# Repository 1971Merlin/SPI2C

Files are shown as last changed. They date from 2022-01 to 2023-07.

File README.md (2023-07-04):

# SPI2C
SPI2C interface hardware and software for the TEC-1 and SC-1 family of Z80 single board computers.

The full [construction article](SPI%20and%20I2C%20Article%20Final.pdf) PDF describes the SPI2C board in detail.

Please see https://github.com/tec1group for information on the TEC computer.

**spi2c_library.asm** contains the current code libraries for interfacing with the SPI2C board. Note the IO ports you choose to use will need to be edite in this file, if you're building for the TEC-1 hardware. The settings are correct for use with the SC-1 as provided.

PS2 Keyboard or Mouse contains sample code and circuit for hooking up a regular IBM PC compatible PS/2 or AT keyboard, or, a PS/2 mouse to the SPI2C.

-------------------------------------------------

The following code examples are early test releases and not all of them use the above library.

**spi_7segs.asm** links an 8 digit, 7-segment display (SPI bus, Duinotech XC-3714) to the SC1. 

**i2c test.asm** code expands on the first sample, adding a DS1307 based clock module (i2c bus, Duinotech XC-4450) which then displays the time on the 7-segment SPI board. The i2c code is also designed to be 'universal', compiling for either the TEC-1 or the SC-1 hardware platforms.

**i2c bus scan.asm** scans the entire i2c bus and displays the address of any detected i2c device on the 7-seg displays. press any key to display the next device. FFh displayed means 'no devices found'.

**5110.asm** displays an image on an SPI bus based 'Nokia 5510' or PCD8544 display, i.e. a standard 84x48 monochrome LCD.

**Game of Life 5110.asm** Game of Life is a cellular automation program developed in 1970. https://en.wikipedia.org/wiki/Conway%27s_Game_of_Life It is a popular routine to reproduce an many computing platforms, as the algorithm is quite simple and memory etc. requirements are also fairly minimal. In this version we use the SPI2C board and the Nokia 5110 LCD display as the output device. The program can be compiled with either a random or a fixed pattern starting point.

**maze 5100.asm** A simple maze program, made famous by the well known Commodore 64 basic code

````10 PRINT CHR$(205.5+RND(1)); : GOTO 10.````

Outputs to the 84x48 "Nokia 5110" LCD display.

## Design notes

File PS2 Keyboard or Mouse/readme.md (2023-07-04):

This is a practical example of putting the SPI2C board to good use. It allows the conection of an AT or PS/2 keyoard, or a PS/2 mouse.

Sample code is provided to read in keystrokes or mouse data, and outputs it to the serial terminal. Note you will need the spi2c_library.asm file from the main SPI2C folder also, to assemble the code yourself.

The following diagram shows how the connectors should be wired. Note that only *ONE* device can be connected at a time - you cannot have both a keyboard and a mouse both connected at the same time.

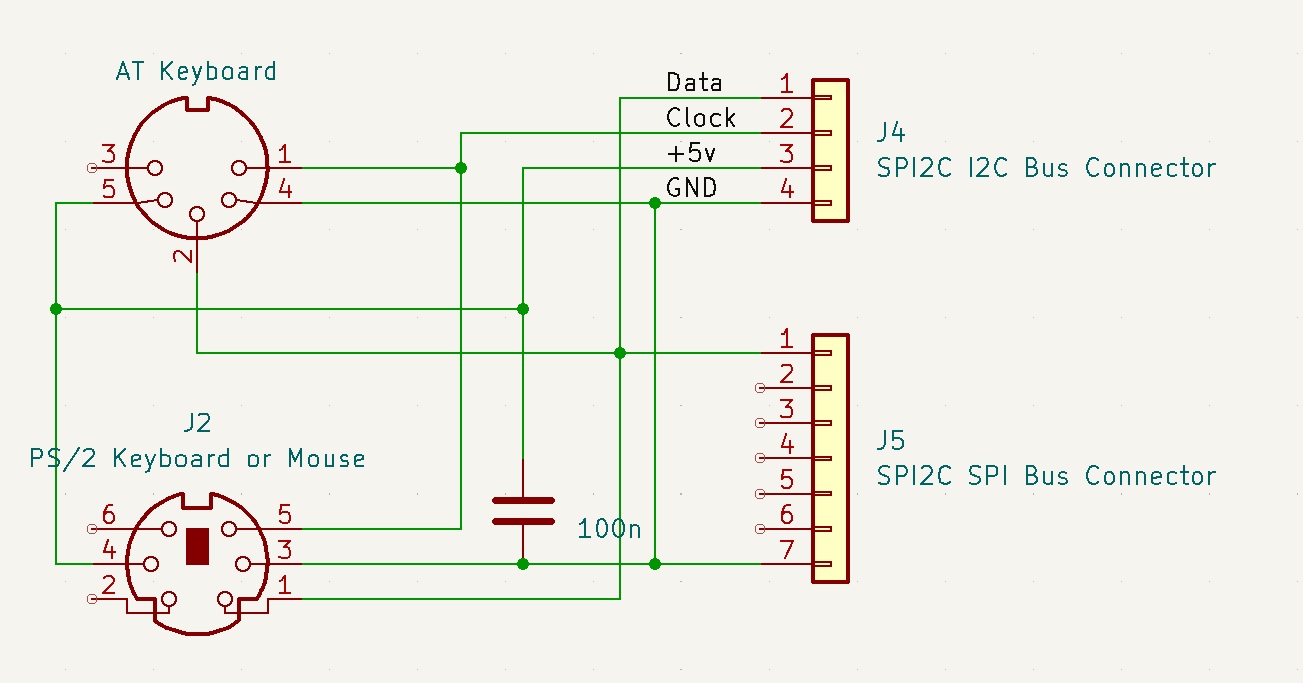
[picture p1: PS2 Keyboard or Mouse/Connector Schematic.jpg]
Connector Schematic


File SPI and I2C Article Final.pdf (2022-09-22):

### Presenting the SPI2C, a simple I/O interface and supporting software for interfacing with

modern peripherals.

### By Craig Hart

One of the limitations of the TEC platform is a lack of 'usable' I/O to communicate with the outside world. TE Issue 14 brought us the I/O board, however this design was a very simple parallel style interface where each I/O pin was either a fixed input or output.
Many modern chips today tend to communicate using bidirectional, serial based signalling protocols – that is, one or two pins are used to transmit and receive data in a serial form. Until now, these devices were not compatible with the TEC-1 or SC-1.
SPI2C implements the two most common interfaces found across a large range of modern peripherals; firstly the SPI or Serial Peripheral Interface bus, and secondly the I

2C
(pronounced I squared C or simply I to C) bus.

In the spirit of TE learning, we have not simply dumped a clever custom chip onto the Z80 bus. Instead, the SPI2C introduces a new design building block for the TEC – a bidirectional IO pin. That is a single pin that can both read and write data under software control. We have built our interfaces using easy to understand 74xxx family TTL logic chips. In this way the entire operation of the design can be understood and followed.
Of course, any hardware is only as good as the software it comes with, and so we are providing supporting software that implements the I

2C

and SPI bus protocols at the most basic level. Full source code is available via Github under an open source license, as are the PCB files. This approach is far more
educational than just ‘talking to a smart controller chip’ or calling a software library you don’t have the source code to.

SPI is a very simple synchronous serial bus. It has a clock(SCLK) line, a chip select(SS) line, and two data lines read(MISO) and write(MOSI).

Don’t be put off by the unfamiliar labels, just mentally substitute (‘In’ or ‘read’ for MISO, and ‘Out’ or ‘write’ for MOSI).
In the above image, the TEC plays the role of Master, and our peripheral device is the Slave. When we say the bus is
synchronous, we simply mean it has a clock(SCLK) line that dictates bus timing.
Data is considered valid when (and only when) the state of the SCLK line changes. Our code can be as fast or slow as we please and it does not matter what frequency the Z80 is running at, or if interrupts are occurring at the same time. The SS line works just like the Chip Select (CS) line we are all familiar with – allowing multiple SPI slave devices to be connected to the bus, but only one device can be active at a time. Each SPI device has its own dedicated SS pin. The MOSI, MISO and SCLK lines are wired in parallel and shared by all devices.
This is where things start to deviate from the familiar TEC world.
The MISO pin is normally held in tristate condition by all devices (nobody is outputting any logic level onto the bus). This is an input pun, so the SPI2C isn’t outputting anything either; therefore a pull-up resistor is supplied to hold the bus at a logic 1 when idle.
Only when a slave device is actively sending data is the pin not tri-stated; the SPI standard says this pin is active LOW, so an SPI slave can pull this pin low to transmit data.
Theoretically, an unlimited number of SPI devices can share a single bus, however there are practical limits to the number of devices; our board offers up to 6 Chip Select lines; hence we can support up to 6 devices in the basic design.
Some slightly non-standard SPI bus devices also have extra control pins for various tasks such as Reset, Backlight enable, mode selection or other custom functions. We can easily support these types of devices by simply adding extra control pins. The SPI2C provides the most common signals.

Duinotech XC-3714: an SPI bus based 8 Digit 7-seg display is available for around $10 from Jaycar etc.

The I

2C bus is a similar yet more advanced version of SPI. With I²C, the whole bus is reduced to just two wires – clock(SCL) and data(SDA).

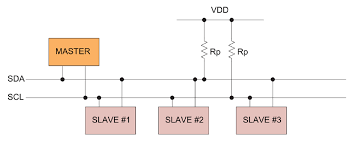
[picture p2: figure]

The bus is also synchronous in nature just like SPI, however a very clever signalling protocol and some smart hardware design is used to eliminate the other control wires completely. Both the clock and data lines use the same active-low-tristate hardware approach as SPI. Chip select is integrated within the bus protocol (each I2C device has a unique 7-bit ‘address’ on the I2C bus), hence the SDA pin performs 3 functions - data in, data out and device select.
SPI offloads all the hard work to software, allowing the hardware to be as simple as possible.

The hardware design can be broken down into several sections, as follows.

The 74HC138 address decoder is functionally similar to the TECs own 74LS138s – except it decodes the IO address range 40h to 7Fh. Note that we ignore address line A0, so every odd port is a duplicate of the preceding even-numbered port. This means port 40h and 41h are an equivalent pair as far as software is concerned (…and port pairs 42h & 43h, 44h and 45h, etc.) so code can address either port and read or write the same device.
Also, since we are ignoring address lines A4 and A5, the I/O ports ‘wrap around’ every 16 addresses, so ports 40h, 50h, 60h and 70h all access the same device.
The reason for this, is that the 74HC138 just doesn’t have enough pins to fully decode just one I/O port. The Z80 has plenty of IO port space so we don’t really care about the overlap.
SC-1
The SPI2C is designed to ‘plug in’ to the SC1’s Expansion connector with no further modifications.

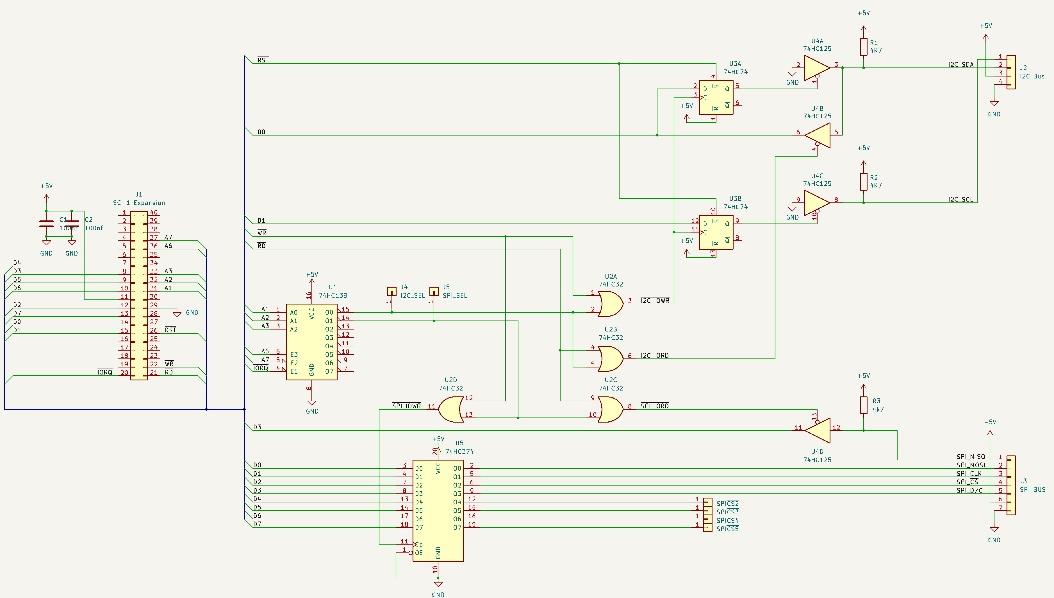
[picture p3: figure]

TEC-1
The 74HC138 chip should be omitted entirely if you wish to use the TEC’s built in IO ports e.g. ports 6 and 7.
Omit the 74HC138 and connect the I2C_SEL and SPI_SEL pins to the TEC’s IO port select pins 6 and 7 instead.

The purpose of the 74HC32 is to take our port select signals from the 74HC138 (or TEC) and combine them with the Z80’s RD and WR signals, to create separate IORead and IOWrite signals.
This is important because different chips are used for the read and write functions, so they need to be selected individually based on whether the Z80 is executing an IN or OUT instruction (IOread or IOwrite cycle).

The 74HC374 is responsible for the write side of the SPI bus.
The SPI_IOWR signal from the 74HC32 enables this chip only when data is written to the SPI port – and all 8 bits are latched by this chip.

Reading from SPI devices is performed by Gate 4 of the 74HC125, and simply gates the MISO pin onto the Z80 data bus during a read cycle. The SPI bus’s MISO pin is held in tri-state (high impedance) mode whenever data is not actively being sent by a slave device, hence this pin is shared by all SPI slave devices.
The 4k7 pull up resistor holds the MISO line high when idle, hence our software will read a ‘1’ whenever the bus is idle. SPI devices only ever output a logic 0 to the MISO pin (*never* a logic 1!!)
Reads are gated onto the Z80 data bus to bit D3 by the 74HC125 in

SPI2C Circuit Diagram response to a decoded IORead cycle.

The I²C controller is a little more complex than SPI. I

2C pins are
active low; therefore held high by pull-up resistors (devices tri-state) whenever idle.
We need to create an SDA pin that supports the following abilities:
a) Be at logic 1 when idle
b) Output a logic 0 or 1 during our writes
c) Read an input 0 or 1 state from a slave device (and not our own previous output) during reads
d) Be independent of the SCL pin
We can’t simply use a 74HC374 here as it is not bidirectional and other 74HC24x family chips won’t suit either as we can’t address pins individually (e.g. have one pin as an output at the same time another pin is set as an input).
To overcome these limitations, we have created two independent one-bit latches using a 74HC74 flip flop and 2 gates from the 74HC125 as our tri-state buffers.
SDA pin
Firstly, the 74HC74 latches our write of bit D0.
If our write is a logic 1, the I²C bus is placed into tri-state as the 7HC74’s output latches this value and the logic 1 sets the HC125’s output to tri-state mode. Since the slave devices are also idle/tri-state, and the 4k7 resistor pulls the bus up to logic 1.
If we write a logic 0, this is latched by the 74HC74 and then a 0 is gated onto the bus by the 74HC125. Note the input of the 74HC125 is wired to ground – hence we can only ever output a 0 to the I2C bus, never a 1.

Input is the same as for SPI – the other 74HC125 gate simply gates the SDA line directly onto the Z80 data bus during an IORead.
The observant amongst you would have noted – to read valid data from the SDA pin, we need to first output a ‘1’ to the SDA pin, in order to set it to tri-state mode; otherwise a bus short
could occur.
The Z80 reset line sets the 74HC74 flipflop to a logic 1 so as to ensure the I2C bus is tri-stated at power up. Our software should also
ensure a bus clash never
occurs.
SCL pin
The SCL pin works the
same way as the SDA pin,
except it is only ever
driven as an output, so we don’t need a ‘125 gate on
this pin, and any data read
of this bit will be undefined.

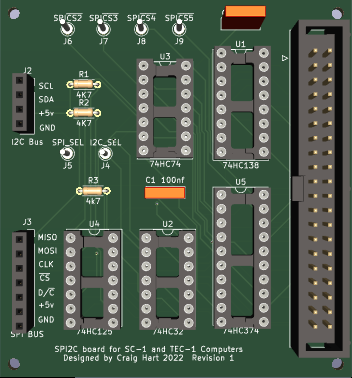
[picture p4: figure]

Any seasoned TEC builder should find assembly straight forward; simply load the parts onto the PCB as shown, the order isn’t critical. However, first decide if you will be building the SC1 version or the TEC version.

The SC1 version is easy – fill all components as shown. The board is designed to plug directly to the expansion header on the SC-1.

Omit the 74HC138 and instead connect I2C_SEL and SPI_SEL pins to the TEC’s IO port select pins for ports 6 and 7.
As the board uses a 40 pin Z80 bus header you will also need to pick up various signals from the TEC

Expansion port and the Z80 CPU. Some soldering to the TEC PCB will be required to pick up all the required signals.
Alternatively, use Craig Jones’ TEC CPU riser board to create an SC-1 style expansion bus connector.
U1 | 74HC138 | (SC-1 only)
U2 | 74HC32
U3 | 74HC74
U4 | 74HC125
U5 | 74HC374
C1 | 100nF
C2 | 100nF
R1 | 4.7k
R2 | 4.7k
R3 | 4.7k
J1 | 40 pin IDC connector
J2 | 4 pin SIL header
J3 | 7 pin SIL header
J4-J9 single pin header

IC Sockets
3 | 14 pin
1 | 16 pin
1 | 20 pin
1 | SPI2C PCB
1 | 40 pin IDC Cable

The SPI2C PCB

The key to this project is the really the software; the hardware itself simply handles the electrical signals, and all the smart control is in the software alone.
The latest versions of all the software as well as schematic, PCB design, supporting datasheets etc. are available at my GitHub site https://github.com/1971Merlin/SPI2C A detailed line by line description of the software is beyond this article, however a quick review as follows:

This program tests basic SPI bus functionality, using a MAX7219 8 digit 7-segment display module such as the Duinotech XC-3714 which is readily available from Jaycar for around $10.
The program simply scrolls a display buffer in RAM across the displays, but it demonstrates several code blocks in doing so – initializing and writing to the SPI bus, as well as managing a simple display buffer.
As a side note, it’s mazing that you can buy EIGHT 7-seg displays, on a PCB, assembled, with a controller chip, pin headers etc. for just ten dollars. To build this yourself from discrete parts would be many times more expensive – hence the value in using these cheap modules and leveraging the wealth of products already out there flooding the Arduino market.

This program builds on spi_7segs, adding support for an I

2C bus based
DS1307 Real Time Clock chip – again we are using the Duniotech XC4450 from Jaycar.
The program implements a simple clock reading from the DS1307 and displaying the time/date on the

MAX7219 displays as well as on the internal 7-seg displays so you can check it is working correctly. Obviously this program introduces the I

2C bus control code, however it is a much more ‘complete’ program that includes several utility routines such as display scanning, keyboard polling. The program contains conditional assembly directives to assemble for either the SC-1 or TEC-1 hardware platforms.

This program uses a cheap 84x48 mono LCD display, also known as a ‘Nokia 5110” display driven form the SPI bus. Once again this is a Jaycar part XC4616 and is less than $20. John Conway’s Game of Life is presented on the LCD, and is a good example of a practical use for the system as a whole.

The code is written and assembled into the final binary using Telemark TASM – the table based assembler, which is available from
https://www.ticalc.org/archives/files/fileinfo/250/25051.html (https://www.ticalc.org/archives/files/fileinfo/250/25051.html)
To compile the code, simply run tasm -80 -g0 filename.asm from a command prompt, and it will output an .obj file in intel hex, and a .lst file which is a text file showing the commented listing and the hex bytes to be keyed in.
I personally take TASM generated .obj file and use the the SC-1’s serial upload feature (Fn 1) to upload the code from a PC at 4800 baud.

Of course you can type the HEX bytes in by hand and write your code with pen, paper and opcode lookup tables the way TE did, but you quickly realise this is not
practical | when | developing
software.
I strongly suggest and encourage use of a modern development environment, so you can focus on writing the software and not mundane tasks like looking up opcodes.
There are numerous development platforms such as Oshonsoft.com and asm80.com available online.

Having introduced some basic routines and the ‘raw’ code, well the sky is the limit in terms of possibilities.
Just about any SPI or I²C bus device can be used – and my goal is to build over time a library of subroutines to support numerous devices.
Any code will of course be published on Github as it is developed. And I encourage readers to become familiar with the various TEC Github resources available in the community. Beyond this, I encourage and welcome you, dear reader, to start experimenting. Feel free to provide feedback, bug fixes and new features via Github and the TEC-1 Facebook group, and lets see what we can grow from here.
I look forward to receiving your input.

All source code and examples are available from my Github

## https://github.com/1971Merlin/SPI2C

All my software is free, open source and GPL licensed.

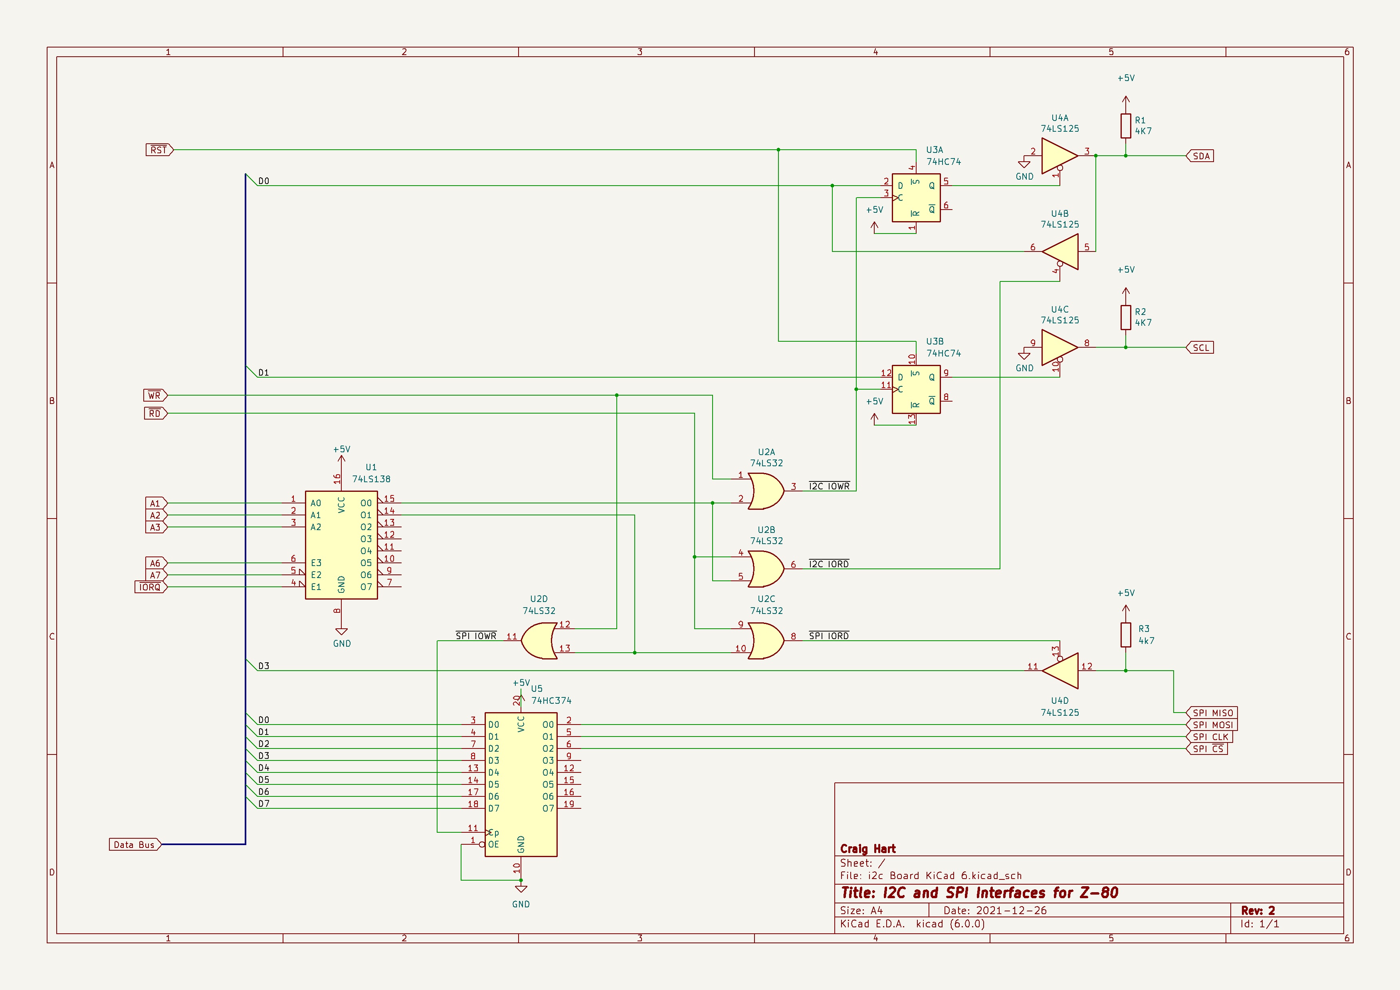
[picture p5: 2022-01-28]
i2c board rev 2.jpg

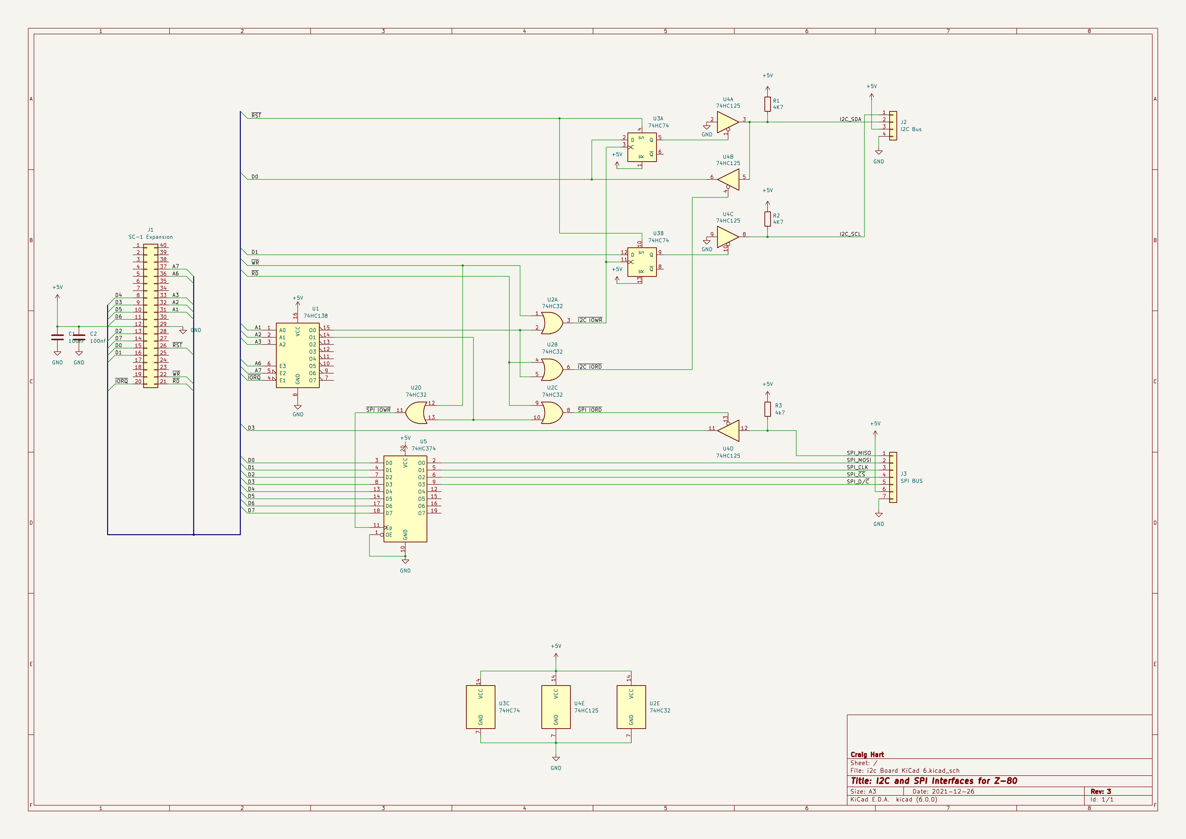
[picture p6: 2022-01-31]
i2c board rev 3.jpg

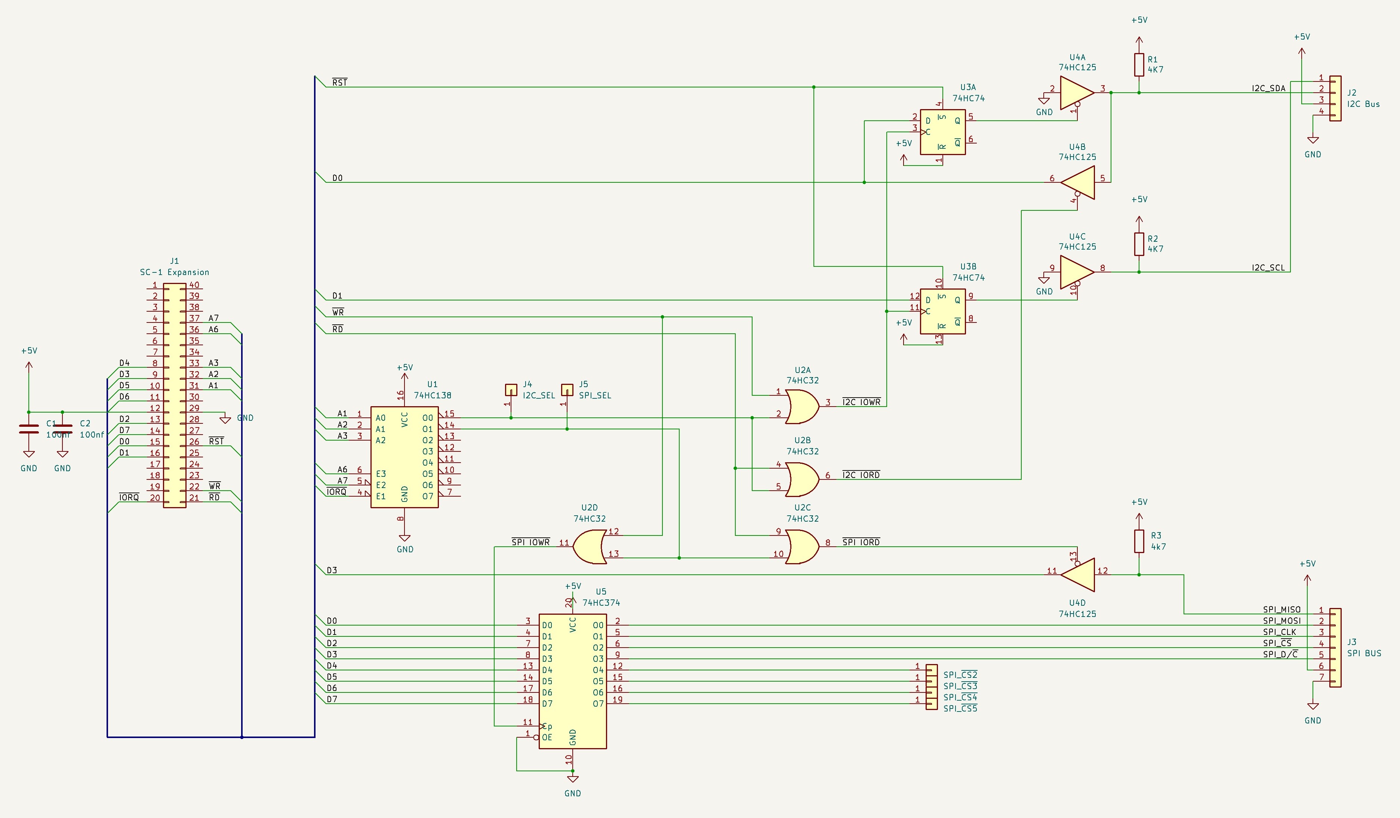
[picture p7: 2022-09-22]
SPI2C Circuit.jpg

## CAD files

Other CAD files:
Maze 5110.obj
PS2 Keyboard or Mouse/ATkeyboard.obj
Game of Life 5110.obj
PS2 Keyboard or Mouse/PS2Mouse.obj
i2c bus scan.obj
5110.obj
i2c test.obj
spi_7segs.obj

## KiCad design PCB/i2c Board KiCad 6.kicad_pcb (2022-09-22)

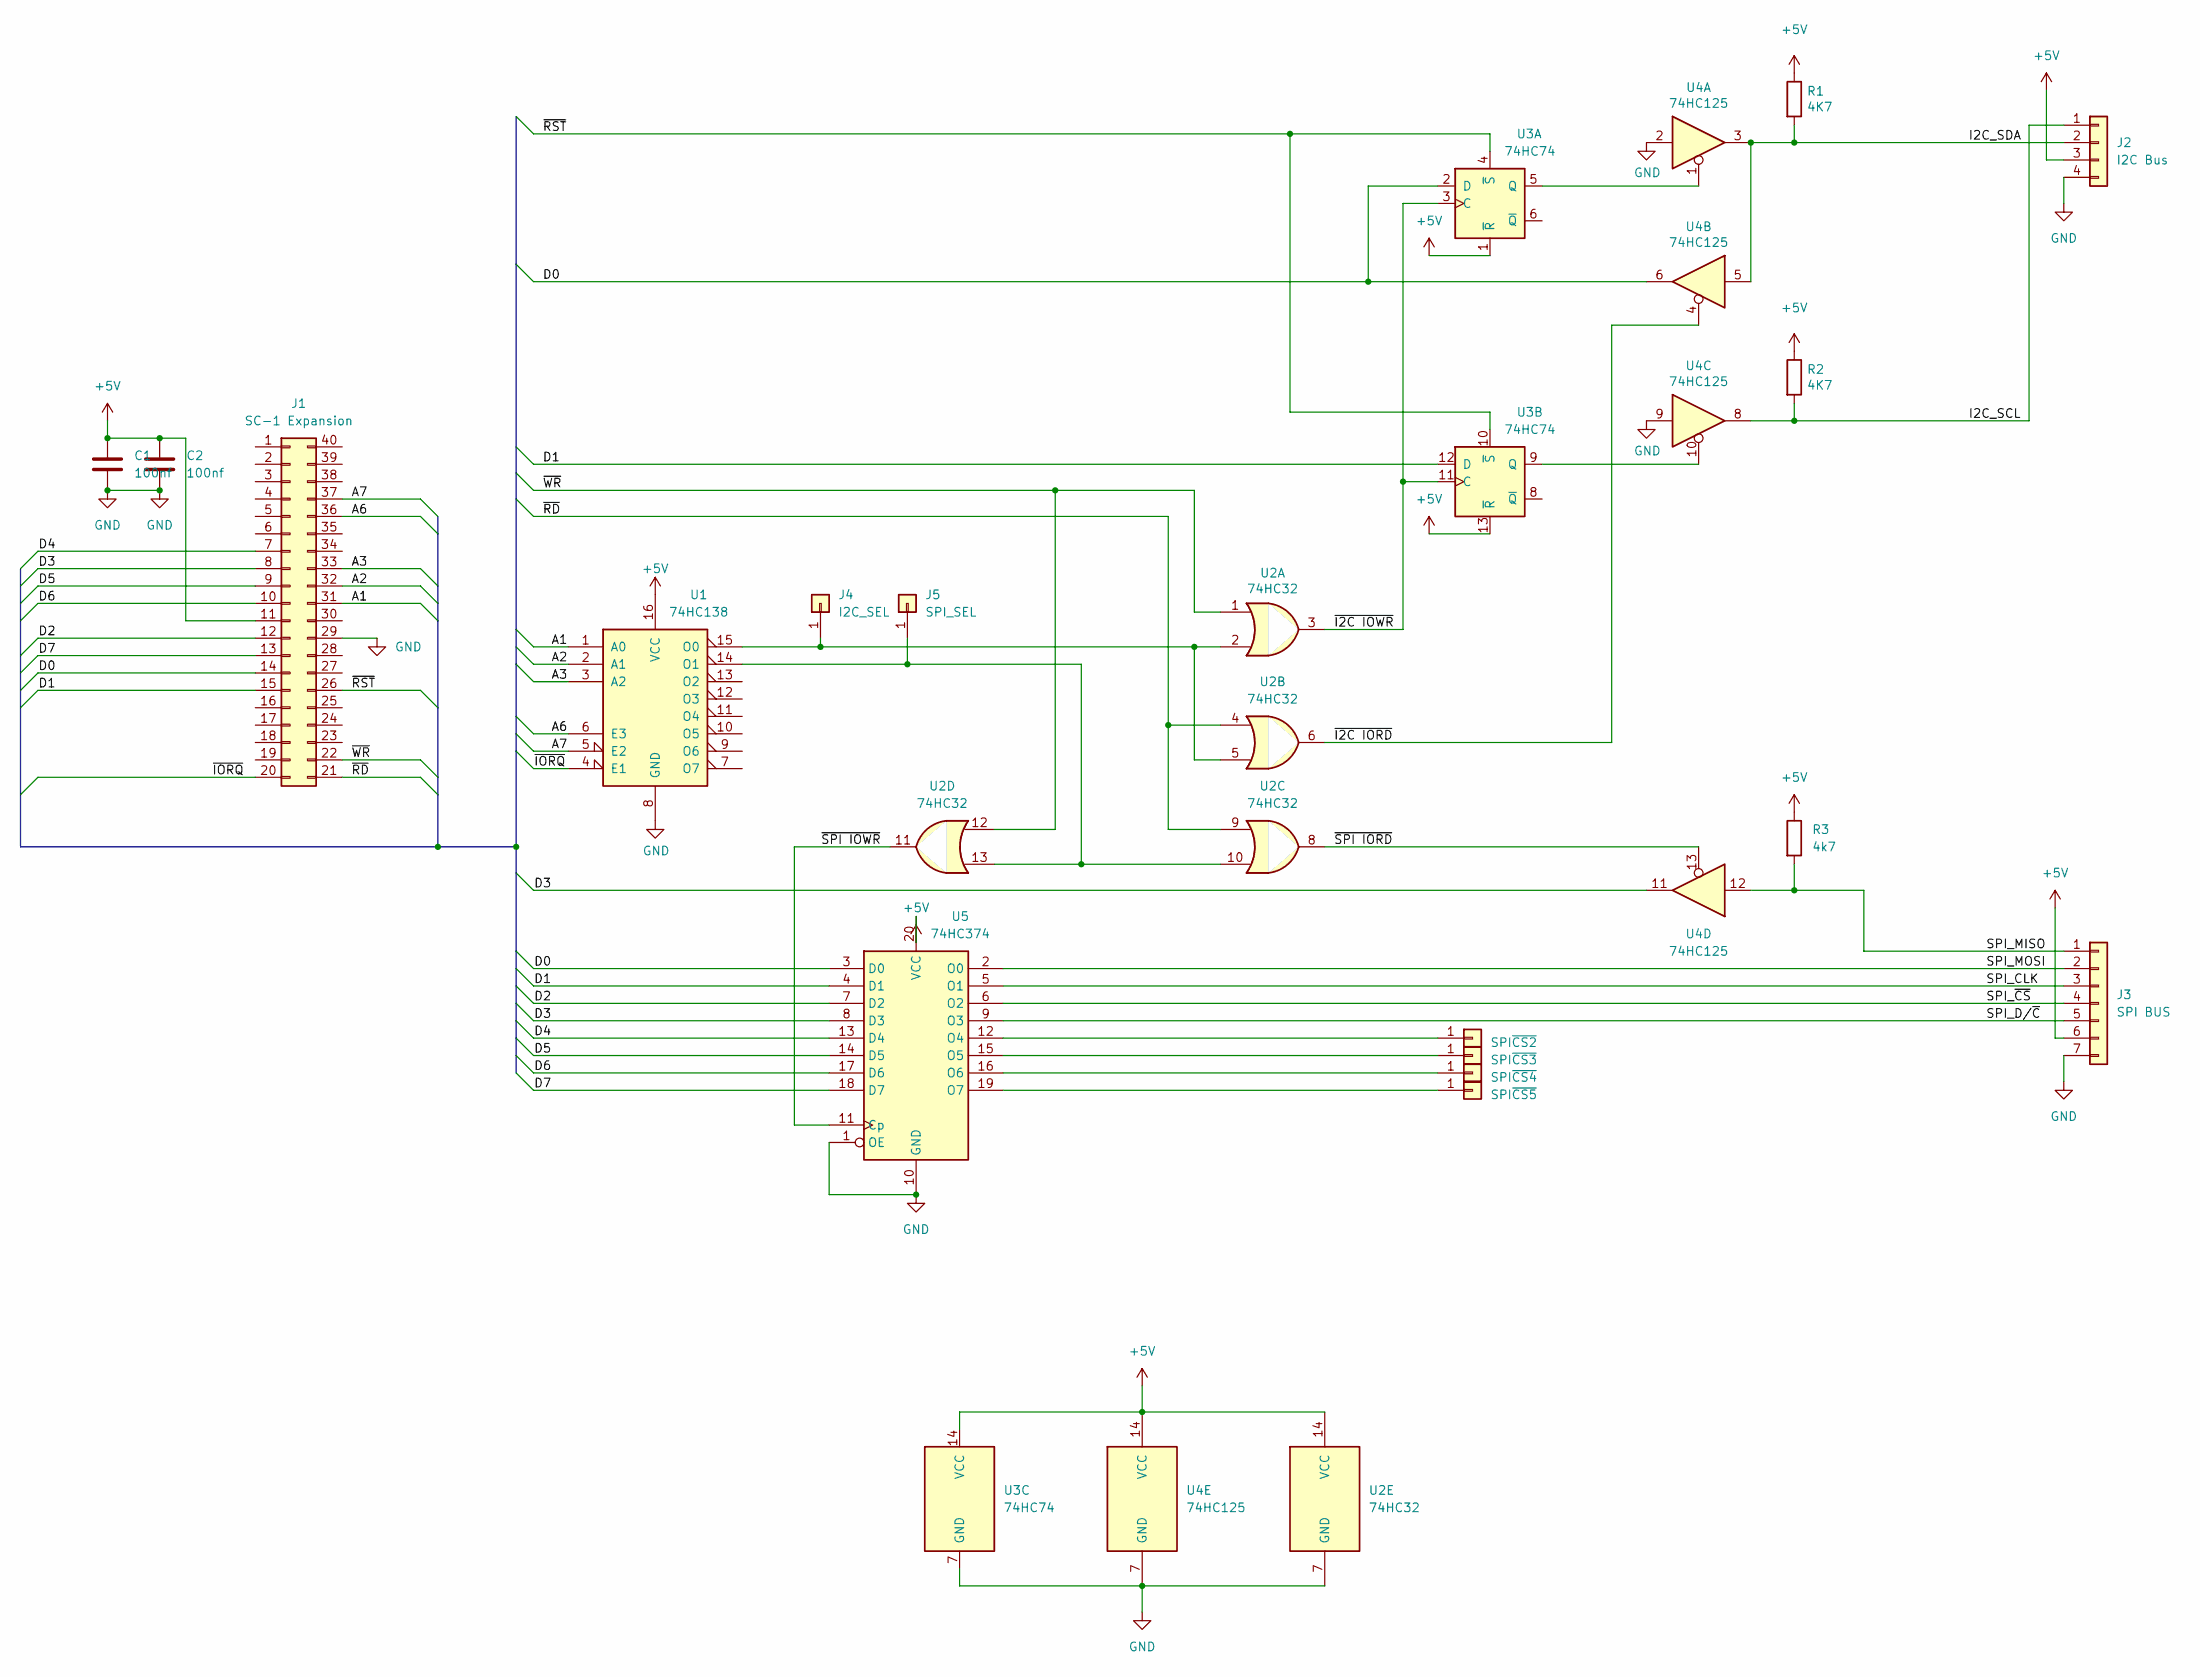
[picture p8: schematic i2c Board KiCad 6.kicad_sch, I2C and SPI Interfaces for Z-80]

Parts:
C1, C2: 100nf; C_Rect_L7.0mm_W2.0mm_P5.00mm
J1: SC-1 Expansion; SC-1 CPU IDC Header
J2: I2C Bus; PinSocket_1x04_P2.54mm_Vertical
J3: SPI BUS; PinSocket_1x07_P2.54mm_Vertical
J4: I2C_SEL; Pin_D1.0mm_L10.0mm
J5: SPI_SEL; Pin_D1.0mm_L10.0mm
J6: SPI~{CS2}; Pin_D1.0mm_L10.0mm
J7: SPI~{CS3}; Pin_D1.0mm_L10.0mm
J8: SPI~{CS4}; Pin_D1.0mm_L10.0mm
J9: SPI~{CS5}; Pin_D1.0mm_L10.0mm
R1, R2: 4K7; R_Axial_DIN0204_L3.6mm_D1.6mm_P5.08mm_Horizontal
R3: 4k7; R_Axial_DIN0204_L3.6mm_D1.6mm_P5.08mm_Horizontal
U1: 74HC138; DIP-16_W7.62mm_Socket
U2: 74HC32; DIP-14_W7.62mm_Socket
U3: 74HC74; DIP-14_W7.62mm_Socket
U4: 74HC125; DIP-14_W7.62mm_Socket
U5: 74HC374; DIP-20_W7.62mm_Socket

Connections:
+5V: C1.1, C2.1, J1.11, J2.3, J3.6, R1.1, R2.1, R3.1, U1.16 (VCC), U2.14 (VCC), U3.1 (~R), U3.13 (~R), U3.14 (VCC), U4.14 (VCC), U5.20 (VCC)
/A1: J1.31, U1.1 (A0)
/A2: J1.32, U1.2 (A1)
/A3: J1.33, U1.3 (A2)
/A6: J1.36, U1.6 (E3)
/A7: J1.37, U1.5 (E2)
/D0: J1.14, U3.2 (D), U4.6, U5.3 (D0)
/D1: J1.15, U3.12 (D), U5.4 (D1)
/D2: J1.12, U5.7 (D2)
/D3: J1.8, U4.11, U5.8 (D3)
/D4: J1.7, U5.13 (D4)
/D5: J1.9, U5.14 (D5)
/D6: J1.10, U5.17 (D6)
/D7: J1.13, U5.18 (D7)
/I2C_SCL: J2.1, R2.2, U4.8
/I2C_SDA: J2.2, R1.2, U4.3, U4.5
/SPI_CLK: J3.3, U5.5 (O1)
/SPI_D/~C: J3.5, U5.9 (O3)
/SPI_MISO: J3.1, R3.2, U4.12
/SPI_MOSI: J3.2, U5.2 (O0)
/SPI_~CS: J3.4, U5.6 (O2)
/~I2C IORD: U2.6, U4.4
/~I2C IOWR: U2.3, U3.3 (C), U3.11 (C)
/~IORQ: J1.20, U1.4 (E1)
/~RD: J1.21, U2.4, U2.9
/~RST: J1.26, U3.4 (~S), U3.10 (~S)
/~SPI IORD: U2.8, U4.13
/~SPI IOWR: U2.11, U5.11 (Cp)
/~WR: J1.22, U2.1, U2.12
GND: C1.2, C2.2, J1.29, J2.4, J3.7, U1.8 (GND), U2.7 (GND), U3.7 (GND), U4.2, U4.7 (GND), U4.9, U5.1 (OE), U5.10 (GND)
unnamed: J4.1, U1.15 (O0), U2.2, U2.5
unnamed: J5.1, U1.14 (O1), U2.10, U2.13
unnamed: J6.1, U5.12 (O4)
unnamed: J7.1, U5.15 (O5)
unnamed: J8.1, U5.16 (O6)
unnamed: J9.1, U5.19 (O7)
unnamed: U3.5 (Q), U4.1
unnamed: U3.9 (Q), U4.10

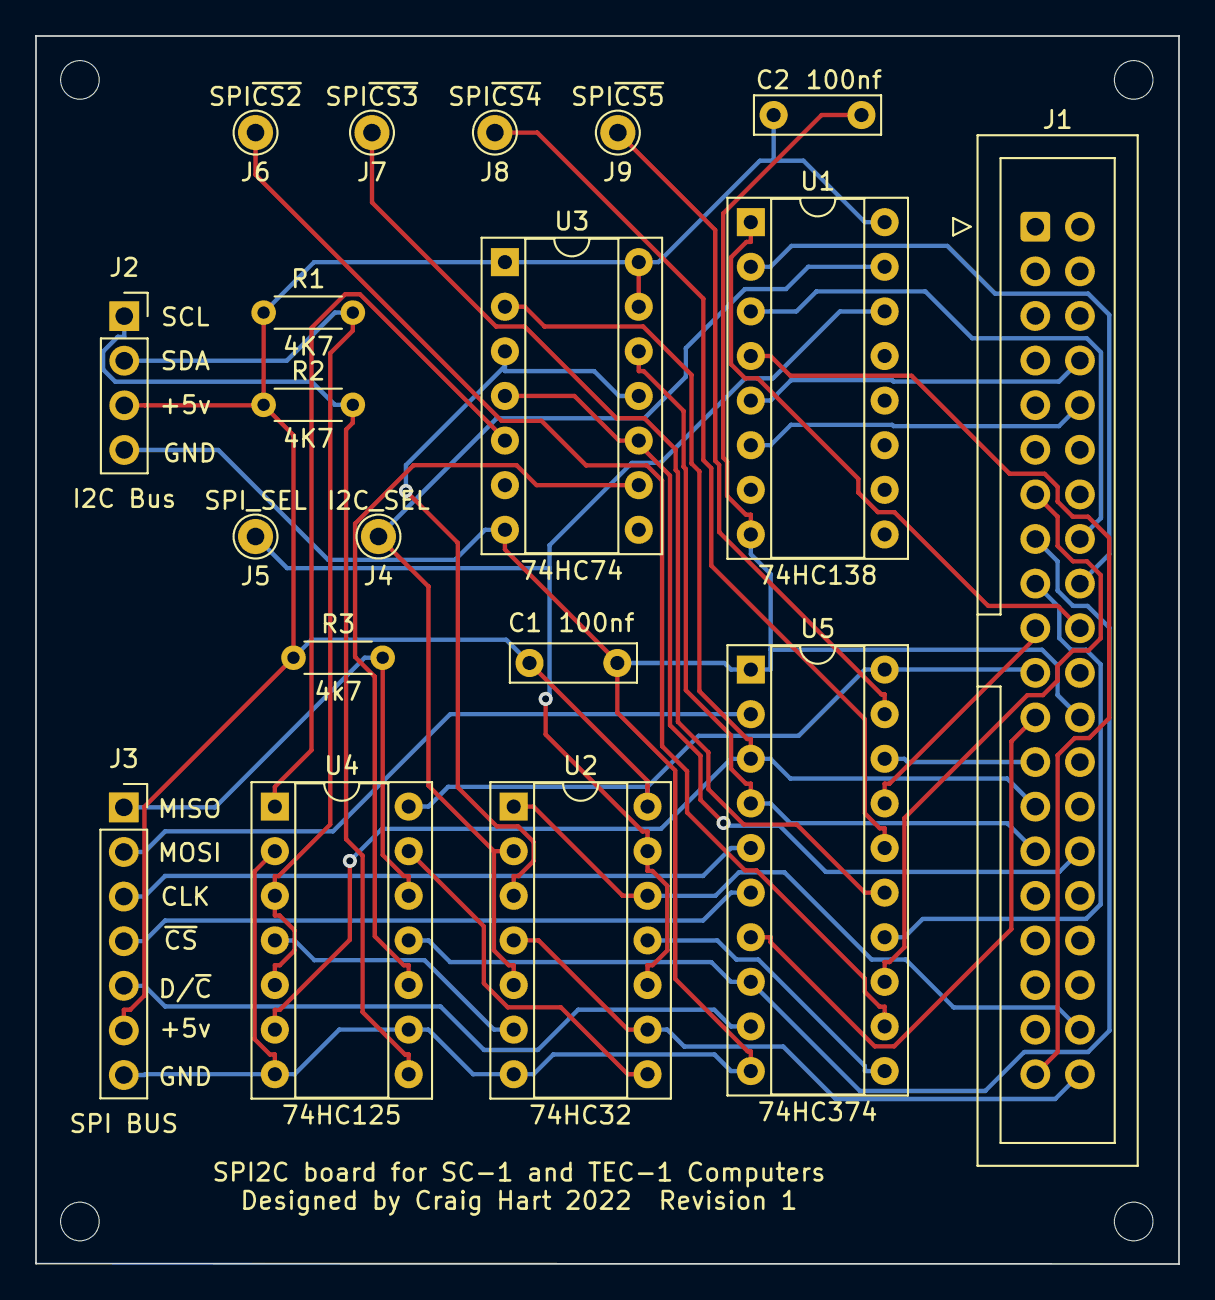
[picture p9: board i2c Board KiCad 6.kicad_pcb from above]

Board: 2 copper layers, 65.1 x 69.9 mm, 23 parts (0 on the bottom side), 38 nets.

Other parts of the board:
Hole1, Hole2, Hole3, Hole4: MountingHole_2.2mm_M2

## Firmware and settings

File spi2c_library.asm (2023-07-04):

; ----------------------------------------------------------------------------
; 	Libraries for SPI2C board.
;
;	Copyright (C) 2023, Craig Hart. Distributed under the GPLv3 license.
;
;	https://github.com/1971Merlin/SPI2C
;
; ----------------------------------------------------------------------------

; ----------------------------------------------------------------------------
;
; Common Parameters
;
; the user should change the ports according to the hardware in use
;
; ----------------------------------------------------------------------------


i2cport	.equ 40h	; IO port our I2C "controller" lives on
			; 40h for SC-1 using the onboard 74HC138
			; user selected for TEC-1

spiport	.equ 42h	; IO port our SPI "controller" lives on
			; 42h for SC-1 using the onboard 74HC138
			; user selected for TEC-1

	
spics1	.equ 0fbh
spics2	.equ 0efh
spics3	.equ 0dfh
spics4	.equ 0bfh
spics5	.equ 07fh



; ----------------------------------------------------------------------------
; I2C Routines
; ----------------------------------------------------------------------------

i2cidle	.equ 03h

i2c_init:
	push af
	ld a,i2cidle	; idle state = SCL and SDA both high
	out (i2cport),a
	pop af
	ret

; ----------------------------------------------------------------------------
; Routine to make the i2c bus active
; ----------------------------------------------------------------------------

i2c_start:
	push af
	ld a,02h	; SCL 1, SDA 0 = start
	out (i2cport),a
	ld a,00h
	out (i2cport),a	; SCL 0, SDA 0 = bus idle active
	pop af
	ret

; ----------------------------------------------------------------------------
; Routine to return i2c bus to idle
; ----------------------------------------------------------------------------

i2c_stop:
	push af
	ld a,01h	; SCL 0, SDA 1 = stop
	out (i2cport),a
	ld a,03h
	out (i2cport),a	; SCL 1, SDA 1 = bus idle inactive
	pop af
	ret

; ----------------------------------------------------------------------------
; Routine to transmit a byte on the i2c bus
;
; enter  d = byte to send
; return d bit 0 = result; 0 = accepted/OK; 1 = ignored/no device
; ----------------------------------------------------------------------------

i2c_txbyte:
	push af
	push bc

	ld b,8		; 8 bits

txbyte1:
	ld a,00h	; prep CL=low, data = ?
	rlc d		; set CF = data
	adc a,a		; set bit 0 to our data
	out (i2cport),a	; SDA=data, SCL = 0

	set 1,a		; Pulse SCL high
	out (i2cport),a
	res 1,a		; and SCL low again
	out (i2cport),a

	dec b
	jr nz, txbyte1

; get ACK since we did a set address command --
; if the device is there we should get an answer bit = 0

rxack:	ld a,03h	; SET SCL = 1 (leave data high = bus free for response)
	out (i2cport),a
	in a,(i2cport)	;get result; 0 = response received
	ld d,a		; store d=result
	ld a,01h	; SCL = 0, SDA = 1
	out (i2cport),a

; d holds our result, bit zro should be a 0 if an ACK received

	pop bc
	pop af
	ret

; ----------------------------------------------------------------------------
; Routine to receive a byte from the i2c bus
;
; return d = result
; ----------------------------------------------------------------------------

i2c_rxbyte:
	push af
	push bc

	ld b,8		; 8 bits
	ld d,00h	; (our data to be read)

rxbyte1:
	ld a,01h	; prep SCL=low, data = high (tristate output)
	out (i2cport),a	; SDA=data, SCL = 0

	ld a,03h	; SCL = 1, SDA = 1
	out (i2cport),a

	in a,(i2cport)	; read bit (they send us SDA)
	rrc a		; store into CF
	rl d		; and read into d

	ld a,01h
	out (i2cport),a	; SCL = 0, SDA = 1 (tristate output)

	dec b
	jr nz, rxbyte1

; send ACK since we read a byte

txack:	ld a,01h	; Setup ACK pulse SCL=0 with SDA=1
	out (i2cport),a
	ld a,03h	; Send ACK SCL = 1, SDA = 1
	out (i2cport),a
	ld a,01h	; lower SCL; idle ready state
	out (i2cport),a

	pop bc
	pop af
	ret


; ----------------------------------------------------------------------------
; Routine to receive an AT keyboard byte from the i2c bus
;
; return a = result
; ----------------------------------------------------------------------------

i2c_ATrx:

	call rxAT	; get the start bit and discard it

	ld b,8		; 8 bits
	ld d,00h	; (our data to be read)

ATbits:	call rxAT	; get 8 data bits
	djnz ATbits

	ld c,d		; backup for later

	call rxAT	; get parity bit and discard it
	call rxAT	; get stop bit and discard it

	ld a,c		; restore value

	ret




rxAT:

rxAT1:	in a,(spiport)	; read
	and 08h
	jp nz,rxAT1	; wait for clk to go low

	in a,(i2cport)	; read bit 0 == data
	rrca		; bit 0 into carry
	rr d		; carry into d bit 7, shifting right each time

rxAT2:	in a,(spiport)	; wait for clock to go high
	and 08h
	jp z,rxAT2

	ret





; ----------------------------------------------------------------------------
; Routine to transmit an AT keyboard byte from the i2c bus
;
; d = byte to transmit
; ----------------------------------------------------------------------------

i2c_ATtx:

	ld c,0

	ld a,d
	or a			; set parity bit
	jp po,noparity

	ld c,1

noparity:
	ld a,01
	out (i2cport),a		; CLK low (bit 1) data high (bit 0)

	ld b,09h			; delay 100us
grabck:	djnz grabck

	ld a,00			; both low
	out (i2cport),a
	
	nop
	nop
	nop
	nop

	ld a,02		; CLK high data low; start bit
	out (i2cport),a

	call txAT1	; wait ack.


	ld b,8		; now send 8 data bits
	
ATbit2:	call txAT
	srl d
	djnz ATbit2

	ld d,c		; send parity  bit
	call txAT

	ld a,03		; back to idle
	out (i2cport),a


	call rxAT
	call rxAT

;	ld b,0fh	; small delay
;ignore:	djnz ignore
	
	
	ret


txAT:	ld a,d
	or 2		; keep CLK high our side, set data bit =b0
	out (i2cport),a	; set bit 0 == data

txAT1:	in a,(spiport)
	and 08h
	jp z,txAT1	; wait for clk to go high


	
txAT2:	in a,(spiport)	; wait for clock to go low
	and 08h
	jp nz,txAT2

	ret
	



; ----------------------------------------------------------------------------
; SPI Routines
; ----------------------------------------------------------------------------

spiidle	.equ 0f4h	; Idle state

; SPI port bits
;
; bit 0 - MOSI/MISO
; bit 1 - CLK
; bit 2 - CS1
; bit 3 - D/C
; bit 4 - CS2
; bit 5 - CS3
; bit 6 - CS4
; bit 7 - CS5

; ----------------------------------------------------------------------------
; SPI initialization code starts here; call once at start of code
;
; idle state == 1111 0100  === MOSI, D/C and CLK low, CSx all high
; ----------------------------------------------------------------------------

spi_init:
	push af
	ld a,spiidle	; Set idle state
	out (spiport),a
	pop af
	ret

; ----------------------------------------------------------------------------
; Routine to send byte to the SPI bus
;
; c = SPI CS pin required (use the spics EQUs above)
; d = command/data 00 = command, 08 = data
; e = data byte
;
; no results returned, no registers odified
; ----------------------------------------------------------------------------

spi_wr:	push af
	push de
	call spi_wrb
	jr spi_done
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

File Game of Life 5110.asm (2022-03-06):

; ----------------------------------------------------------------------------
;
;	Game of Life for TEC SPI2C board with Nokia 5110 LCD
;
;	Designed to compile for the TEC-1 or SC-1 as the target machine
;
;	Assemble with TASM using the command line options -80 -g0
;
;	Copyright (C) 2022h, Craig Hart. Distributed under the GPLv3 license
;
;	https://github.com/1971Merlin/SPI2C
;
; ----------------------------------------------------------------------------


; ----------------------------------------------------------------------------
; conditional defines - set the target machine platform
; ----------------------------------------------------------------------------


#define debug

; #define random


; using spi2c's onboard 74ls138 IO ports
spiport	.equ 42h

; start address for SC-1 code. change to 0900h for TEC-1
	.org 2000h



#ifdef debug

; SC-1 7-seg ports
disscan .equ	85h
disseg	.equ	84h

#endif


; ----------------------------------------------------------------------------
; hardware initialization code starts here
; ----------------------------------------------------------------------------

; reset spi bus to idle state
	ld c,spiport	; reset CS = 1
	ld a,0ffh	; Raise CS
	out (c),a


; write init to the 5110 display

	ld e,21h		; complex mode
	ld d,00h
	call spi_wr

	ld e,0b9h		; set vOP
	ld d,00h
	call spi_wr

	ld e,04h		; temp coeficcient
	ld d,00h
	call spi_wr

	ld e,14h		; lcd bias
	ld d,00h
	call spi_wr


#ifndef random

; setup our starting point life
; first clear buffer b

	ld bc,503		; n-1
	ld hl,buffb
	ld de,buffb
	inc de
	ld (hl),0		; zero fill
	ldir


; seed the starting point into the buffer

	ld b,42
	ld c,31
	ld a,1
	call putpixel

	ld b,43
	ld c,31
	ld a,1
	call putpixel

	ld b,44
	ld c,31
	ld a,1
	call putpixel

	ld b,44
	ld c,32
	ld a,1
	call putpixel

	ld b,44
	ld c,33
	ld a,1
	call putpixel

	ld b,42
	ld c,32
	ld a,1
	call putpixel


; copy buffb to buffa because putpixel goes to buffb
	ld bc,504
	ld hl,buffb
	ld de,buffa
	ldir

#endif


#ifdef debug

; setup debugging - enable LHD 7-seg display
	ld c,disscan
	ld a,20h
	out (c),a
#endif


#ifdef random

; seed random number generator

	ld a,r			; grab a random number
	ld (rndData),a


; random fill buffa to start the game

	ld bc,504
	ld hl,buffa


floop:	call getrandom

	ld (hl),a
	inc hl

	dec bc
	ld a,b
	or c
	jp nz,floop

#endif


; ----------------------------------------------------------------------------
; main program loop
; ----------------------------------------------------------------------------


mainloop:

; write buffer a to display
; setup LCD

	ld e,20h		; simple mode
	ld d,00h
	call spi_wr

	ld e,40h		; Y = 0
	ld d,00h
	call spi_wr

	ld e,80h		; X = 0
	ld d,00h
	call spi_wr

	ld e,0ch		; normal mode
	ld d,00h
	call spi_wr

; Send pixels to 5110 display from buffer a
	ld bc,504
	ld hl,buffa

fillcd:	ld a,(HL)
	ld e,a
	ld d,08h
	call spi_wr

	inc hl
	dec bc

	ld a,b
	or c
	jr nz, fillcd



; perform an iteration of G.O.L. to buffer B

; first clear buffer b to all zeros

	ld bc,503		; n-1
	ld hl,buffb
	ld de,buffb
	inc de
	ld (hl),0		; zero fill
	ldir


; now iterate each cell and test it
; we skip the edges as then we don't have to do bounds checking
; edges are always 0's...dead.

	ld h, 1			; x=1

touter:
	ld l, 1			; y=1


#ifdef debug
	ld c,disseg
	ld a,(flag)
	xor 01h
	ld (flag),a
	out (c),a
#endif

tinner:

#ifdef debug
	ld c,disseg
	ld a,(flag)
	xor 08h
	ld (flag),a
	out (c),a
#endif

; test a pixel block to see if neighbours are alive or dead

	ld d,0		; result count

; top row
	ld b,h	; x-1
	dec b
	ld c,l	; y-1
	dec c

	call getpixel
	add a,d		; increment result
	ld d,a		; and store it
	inc b

	call getpixel
	add a,d		; increment result
	ld d,a		; and store it
	inc b

	call getpixel
	add a,d		; increment result
	ld d,a		; and store it

; bottom row
	ld b,h	; x-1
	dec b
	ld c,l	; y+1
	inc c

	call getpixel
	add a,d		; increment result
	ld d,a		; and store it

; optimization - if already >3, no need to do more checks
	cp 4
	jr nc, nostore

	inc b
	call getpixel
	add a,d		; increment result
	ld d,a		; and store it

; optimization - if already >3, no need to do more checks
	cp 4
	jr nc, nostore

	inc b
	call getpixel
	add a,d		; increment result
	ld d,a		; and store it

; optimization - if already >3, no need to do more checks
	cp 4
	jr nc, nostore


; middle row
	ld b,h	; x-1
	dec b
	ld c,l	; y


	call getpixel
	add a,d		; increment result
	ld d,a		; and store it


; optimization - if already >3, no need to do more checks
	cp 4
	jr nc, nostore

	inc b	; x+1
	inc b
	call getpixel
	add a,d		; increment result
	ld d,a		; and store it

; ok now d = number of active neighbour pixels
; >4 = die
; <2 = die
	cp 4
	jr nc, nostore
	cp 2
	jr c, nostore

; so d=2 or 3 now
; are we alive?

	ld b,h
	ld c,l
	call getpixel

; now a = 1 = we are alive
; if live we stay alive, so decision to live made
	cp 1
	jr z, live

; if dead check d = 3
; and make live if so

dead:
	ld a,d
	cp 3
	jr z, live
	jr nostore		; die; no need to write a 0 as we start with buff b = all 0

live:
	ld a,1

store:
	ld b,h
	ld c,l
	call putpixel


; next pixel

nostore:
	inc l
	ld a,l

	cp 2eh				; 2fh = 0..47; needs n-1 due border pixel
	jr nz, tinner

	inc h
	ld a,h
	cp 52h				; 53h = 0..83; needs n-1 due border pixel
	jp nz, touter








; copy buffer b to buffer a ready for next round

	ld bc,504
	ld hl,buffb
	ld de,buffa
	ldir





	jp mainloop


; ----------------------------------------------------------------------------
; Generate a random number 0<=255 return it in A register
; ----------------------------------------------------------------------------

getrandom:
        push    hl
        push    de
        ld      hl,(rndData)
        ld      a,r
        ld      d,a
        ld      e,(hl)
        add     hl,de
        add     a,l
        xor     h
        ld      (rndData),hl
        pop     de
        pop     hl
        ret


; ----------------------------------------------------------------------------
; Get the living or dead flag (1=living) from buff a
; pointer b=x c=y
; return with a = pixel status in bit 0
;
; the pixel buffer is 6 rows of 84 bytes = 504 bytes
; each byte contains 8 pixels
;
; byte = x+(84*(y/8))
; bit = y and 7
; ----------------------------------------------------------------------------

getpixel:
	push bc
	push de
	push hl

	ld d,c		; store Y in d for later

	ld hl,buffa	; setup base pointer
	ld c,b		; add X offset to it
	ld b,0
	add hl,bc


	ld a,d		; work out which row
	sra a
	sra a
	sra a

	ld bc,84	; width of a bitmap row


lp:	or a		; move up the offset; was cp 0
	jr z, nxt

	add hl,bc	; add the offset
	dec a
	jr lp

nxt:	ld a,d		; grab our Y byte back
	and 07h		; mask off bits to work out which bit we want
	ld b,a
	inc b		; set loop counter

	ld a,(hl)	; get the byte that holds our bit
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

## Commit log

2022-01-28 Initial Files
    [spi_7segs.obj]
2022-01-28 Removed unnecessary delay loop
    [spi_7segs.obj]
2022-01-31 Updated Schematic
    Added propper connectors, additional SPI bus pin supproting D/C signal used by many SPI devices.
2022-02-05 Sample code for fully populated SPI2C board
    Sample code for the SPI2C board. Supports the following devices:
    SPI: MAX7219 8-digit, 7-segment display; Duinotech XC-3714 or equivilant
    I2C: DS1307 RTC board; Duinotech XC-4450 or equivilant
    Currnently only runs on the SC-1 but is being programmed to support both TEC-1 and SC-1 via a conditional compile statement.
    [i2c test.obj]
2022-02-06 Code Cleanup, add date function
    Press any keyboard key to toggle between time and date.
    Date format is YY-MM-DD
    [i2c test.obj]
2022-02-09 SetDS1307 chip, cleanups
    Programs the DS1307 chip with some useable values; clock starts at 18:30:00 and date is 07/10/22
    Cleanups of i2c code and removes some unnecessary subroutines
    [i2c test.obj]
2022-02-12 Polled keyboard, more SPI fixes
    Pressing a keyboard key no longer freezes the code
    SPI code optimized for DS1037
    [i2c test.obj]
2022-02-13 Code to support an 84x48 SPI bus based LCD display
    SPI2C board code for the "Nokia 5110" or Philips PCD8544 family of dispalys. e.g. Duinotech XC-4616
    [5110.obj]
2022-02-20 Finds I2C devices by their bus address
    Scans the I2C bus and displays any valid devices by their address on the 7-Seg displays.
    Checks all valid address 00h - 7fh
    Press any key to show the next detected address. Display of FF means no devices detected.
    DS1307 RTC should appear at 68h
    24LC16B, 24C32 etc. Serial SRAMs appear at 50..57h depending on model and wiring.
    Note the Duinotech XC-4450 contains a 24C32N at address 50h as well as the DS1307 at 68h
    [i2c bus scan.obj]
2022-03-06 John Conway's game of Life for SPI2C and 84x48 LCD
    [Game of Life 5110.obj]
2022-04-07 Simple 'maze' for the Nokia 5110 84x48 LCD
    Based on the classic 10 PRINT CHR$(205.5+RND(1)); : GOTO 10 code made famous by the Commodore 64
    [Maze 5110.obj]
2022-09-22 PCB and Circuit high resolution images
2022-09-22 Final Kicad PCB files complete
    [i2c Board KiCad 6.dsn, i2c Board KiCad 6.kicad_pcb, i2c Board KiCad 6.kicad_sch]
2023-07-04 Universal code Library for SPI2C board
2023-07-04 Add shift-keys support
    Added shift support for non-alpha keys, support numeric / and Enter keys.
    [ATkeyboard.obj]
